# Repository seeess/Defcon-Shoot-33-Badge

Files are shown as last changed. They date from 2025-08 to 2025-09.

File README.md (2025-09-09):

# Defcon-Shoot-33-Badge
STLs of the defcon shoot 33 badge. The only supports you should need are for the bolt (printed upside down). Use a smooth plate for the bolt, the rest of the parts can use a textured plate. I used a dynamic layer height, if you print the threads of the bolt and frame with 0.16 or lower the threads have less overhang and come out better and aren't as tight.

Instructions: unscrew the bolts and insert the trigger (they weren't installed for shipping in the vegas heat in case the plastic trigger spring warped)  
Put the tictac container on top.  
Put a rubberband or two around the tictac container and between the trigger and upper receiver to hold the tictacs on.
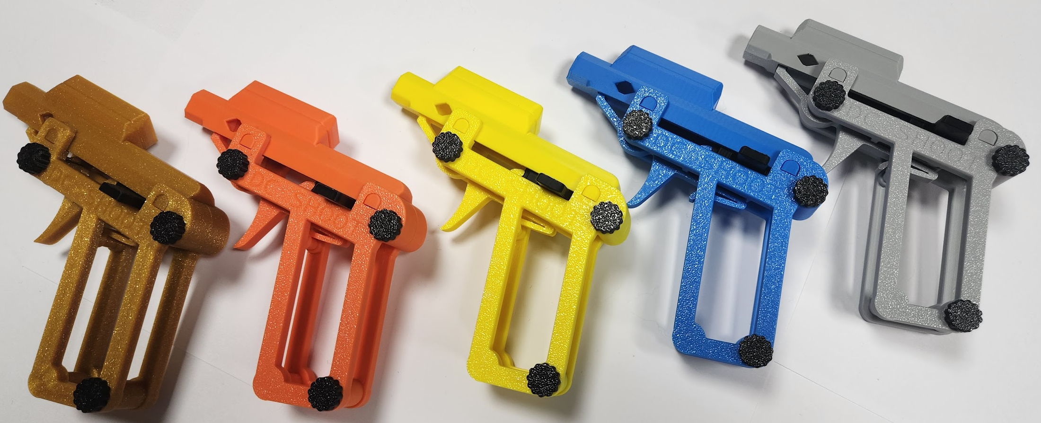
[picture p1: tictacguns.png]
badge pic


Spring details:  
10mm outside diameter, 50mm long uncompressed. Originally I had 0.1mm coil diameter and ~11 turns (the spring almost completely compresses to catch the sear) but this was too strong and breaking some PETG bolts. So I went with 0.8 coil diameter 16 turns

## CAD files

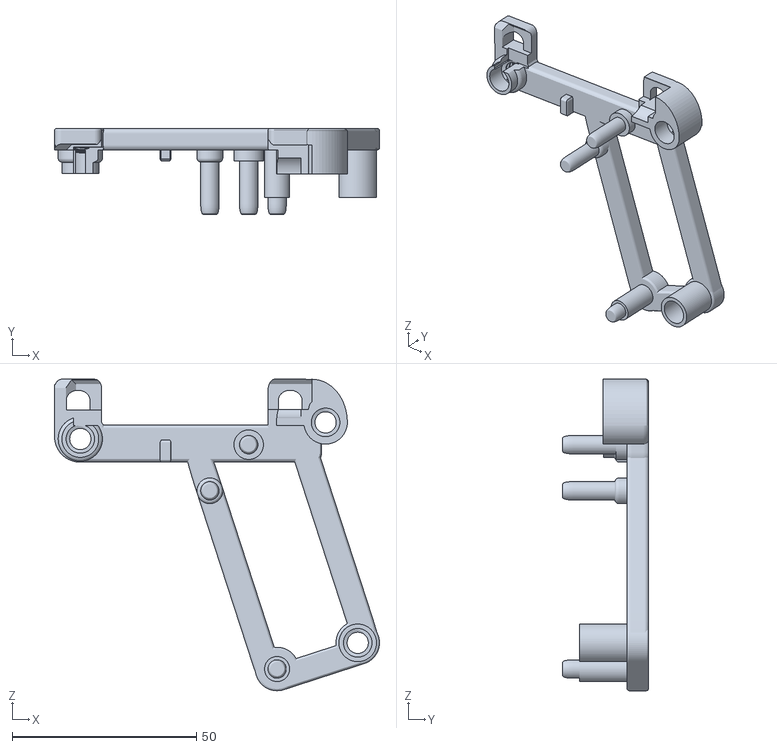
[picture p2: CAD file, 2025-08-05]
right.stl
88.1 x 23.2 x 84.5

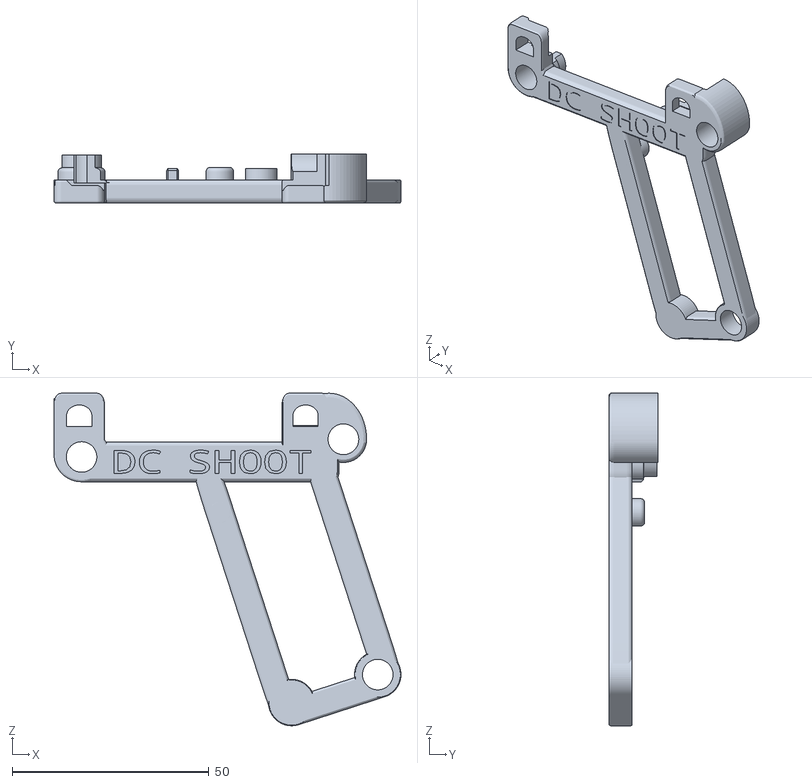
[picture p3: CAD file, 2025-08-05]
left.stl
88.1 x 12.4 x 84.5

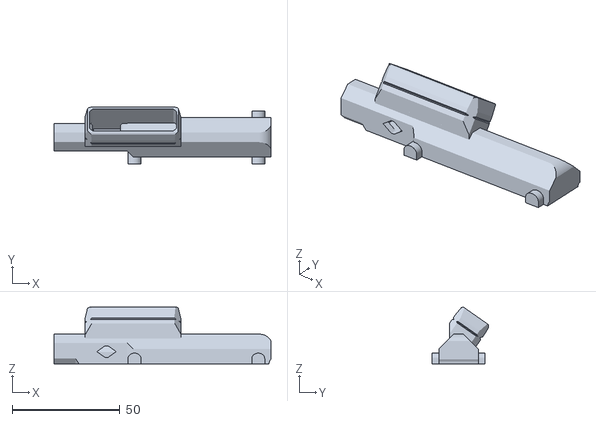
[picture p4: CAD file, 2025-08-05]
upper.stl
100.8 x 26.3 x 26.4

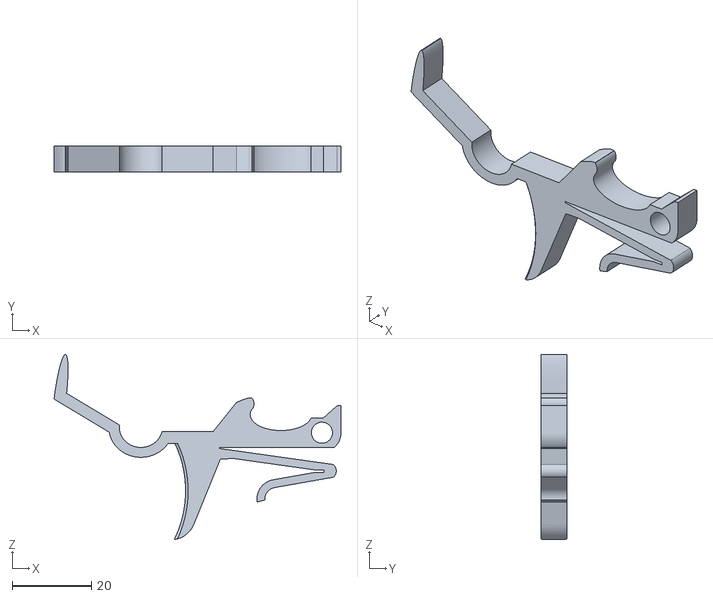
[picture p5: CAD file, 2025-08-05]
trigger.stl
72.4 x 6.60 x 46.7

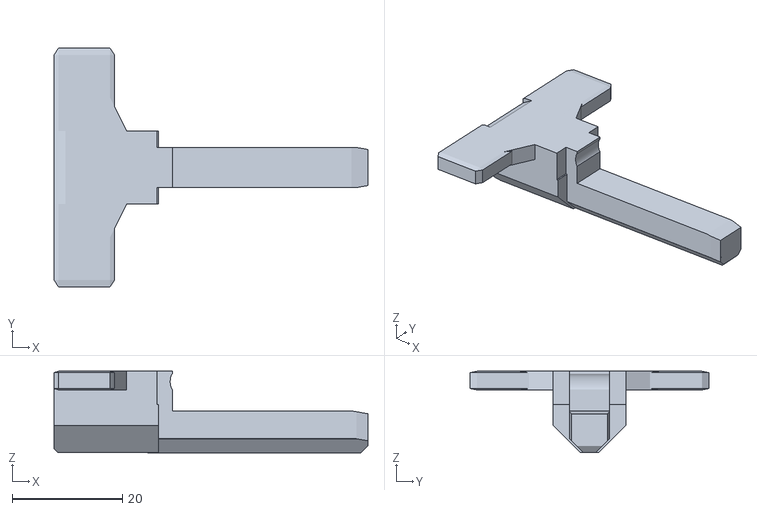
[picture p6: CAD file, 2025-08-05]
bolt.stl
57.0 x 43.4 x 14.8

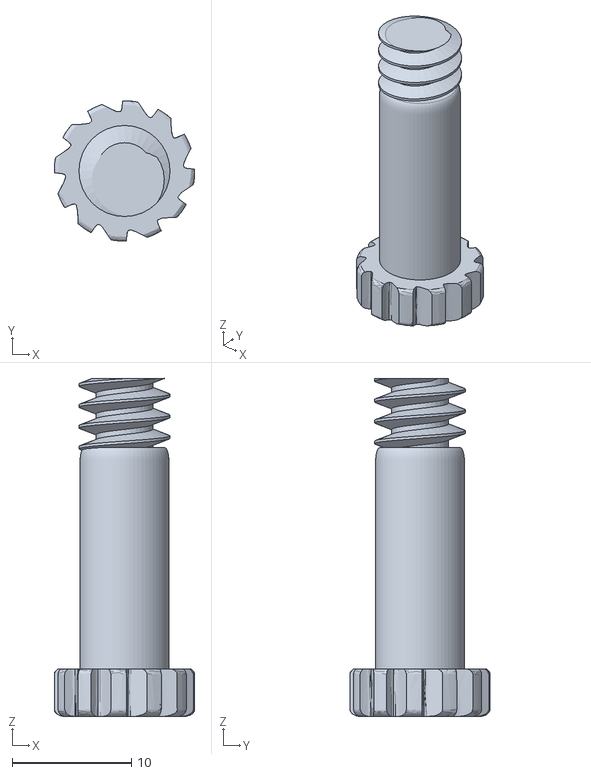
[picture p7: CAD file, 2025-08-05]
screw.stl
11.8 x 11.8 x 28.4
